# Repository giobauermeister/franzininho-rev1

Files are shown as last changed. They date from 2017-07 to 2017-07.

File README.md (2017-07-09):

# Franzininho

Essa é a versão KiCAD da placa Franzininho desenvolvida por Fábio Souza

Veja o projeto original feito no Eagle aqui: https://github.com/FBSeletronica/Franzininho

Uma placa Arduino facil de montar. Possui placa de circuito impresso em face simples e componentes pth. 

Essa placa foi desenvolvida para as atividades no FAB LAB Livre SP durante o Arduino Day 2017 em São Paulo: http://arduinosaopaulo.cc

Você pode facilmente fazer a sua usando uma CNC ou até mesmo métodos caseiros.

É importante usar uma placa de circuito impresso de 2.4 mm para um boo conexão na USB.

# Caracteríticas:

Microcontrolador ATtiny85 DIP, Conector USB na placa, 5 Pinos de I/O, LED de uso geral, LED de POWER

Artigo no Embarcados: https://www.embarcados.com.br/franzininho-um-arduino-para-todos/

# Programação

Para programação na IDE arduino, deve ser gravado o bootloader, conforme exmplicado no post do Mauricio Jabur no Fazedores: http://blog.fazedores.com/attiny85-com-v-usb-como-gravar-o-bootloader-usando-arduino/

# Material para oficinas

Em constução

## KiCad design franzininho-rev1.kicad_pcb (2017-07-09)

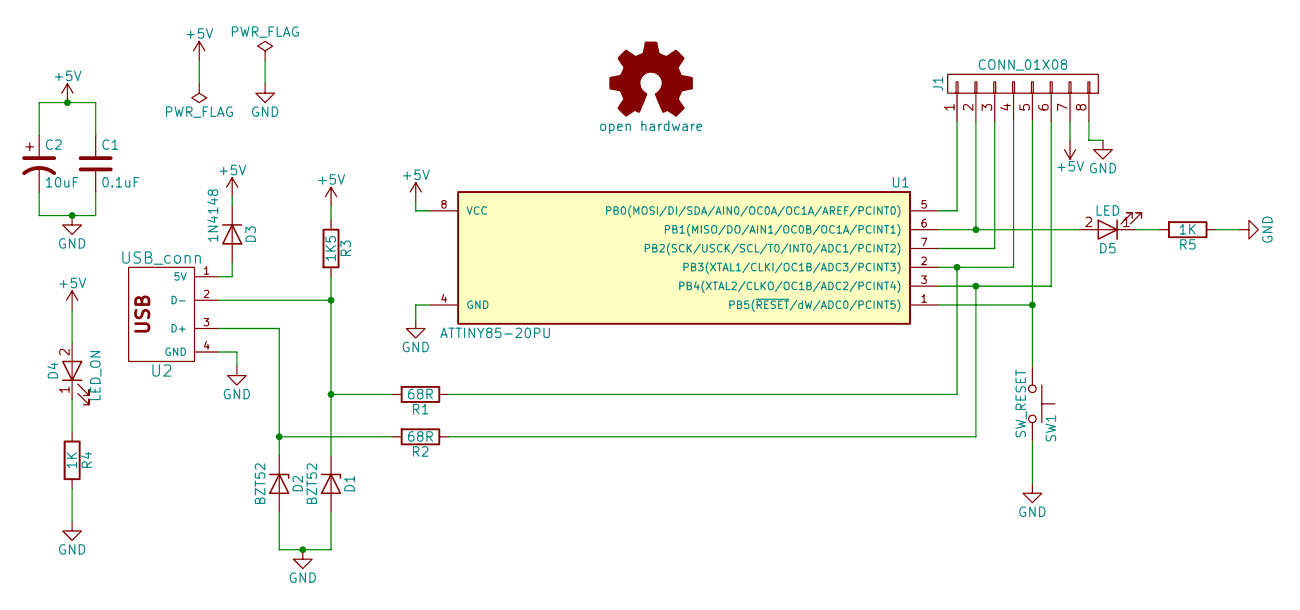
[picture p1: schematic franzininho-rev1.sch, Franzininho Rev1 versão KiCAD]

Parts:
C1: 0.1uF; C_Disc_D3.0mm_W1.6mm_P2.50mm
C2: 10uF; CP_Radial_D5.0mm_P2.50mm
D1, D2: BZT52; D_DO-35_SOD27_P7.62mm_Horizontal
D3: 1N4148; D_DO-35_SOD27_P7.62mm_Horizontal
D4: LED_ON; LED_D3.0mm
D5: LED; LED_D3.0mm
J1: CONN_01X08; Pin_Header_Straight_1x08_Pitch2.54mm
LOGO1: open hardware; OSHW-Logo2_9.8x8mm_SilkScreen
R1, R2: 68R; R_Axial_DIN0207_L6.3mm_D2.5mm_P10.16mm_Horizontal
R3: 1K5; R_Axial_DIN0207_L6.3mm_D2.5mm_P10.16mm_Horizontal
R4, R5: 1K; R_Axial_DIN0207_L6.3mm_D2.5mm_P10.16mm_Horizontal
SW1: SW_RESET
U1: ATTINY85-20PU; DIP-8_W7.62mm
U2: USB_conn; USB_COPPER_2

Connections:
+5V: C1.1, C2.1, D3.1 (K), D4.2 (A), J1.7, R3.1, U1.8 (VCC)
GND: C1.2, C2.2, D1.2 (A), D2.2 (A), J1.8, R4.2, R5.1, SW1.2, U1.4 (GND), U2.4 (GND)
unnamed: D1.1 (K), R1.2, R3.2, U2.2 (D-)
unnamed: D2.1 (K), R2.2, U2.3 (D+)
unnamed: D3.2 (A), U2.1 (5V)
unnamed: D4.1 (K), R4.1
unnamed: D5.1 (K), R5.2
unnamed: D5.2 (A), J1.2, U1.6 (PB1(MISO/DO/AIN1/OC0B/OC1A/PCINT1))
unnamed: J1.1, U1.5 (PB0(MOSI/DI/SDA/AIN0/OC0A/OC1A/AREF/PCI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)
unnamed: J1.3, U1.7 (PB2(SCK/USCK/SCL/T0/INT0/ADC1/PCINT2))
unnamed: J1.4, R1.1, U1.2 (PB3(XTAL1/CLKI/OC1B/ADC3/PCINT3))
unnamed: J1.5, SW1.1, U1.1 (PB5(~RESET~/dW/ADC0/PCINT5))
unnamed: J1.6, R2.1, U1.3 (PB4(XTAL2/CLKO/OC1B/ADC2/PCINT4))

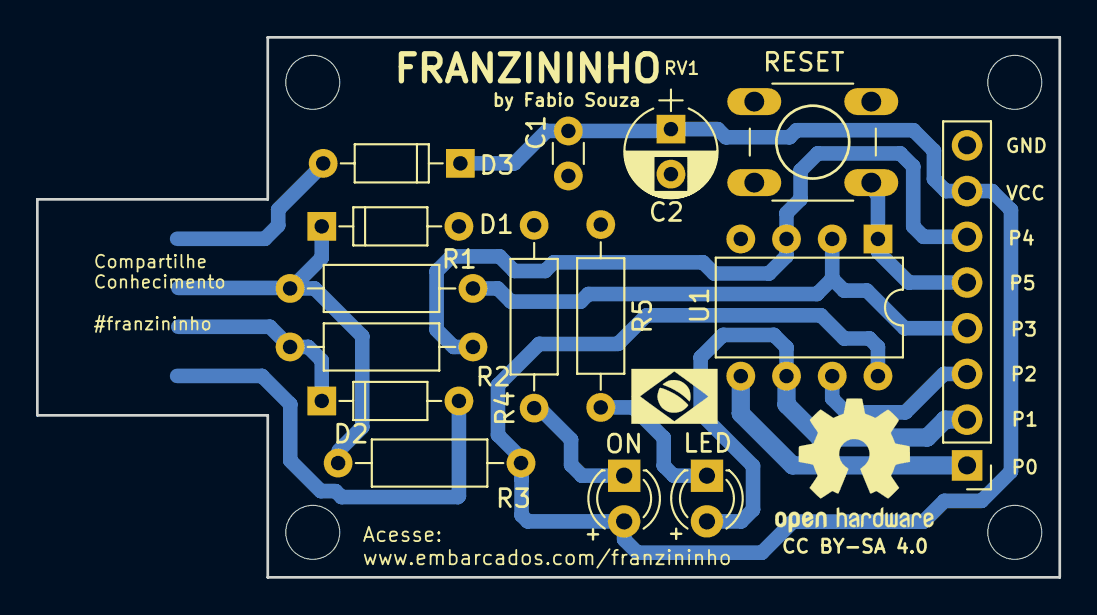
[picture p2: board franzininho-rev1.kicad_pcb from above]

Board: 2 copper layers, 56.8 x 30.0 mm, 17 parts (1 on the bottom side), 13 nets.

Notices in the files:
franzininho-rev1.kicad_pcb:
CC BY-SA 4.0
